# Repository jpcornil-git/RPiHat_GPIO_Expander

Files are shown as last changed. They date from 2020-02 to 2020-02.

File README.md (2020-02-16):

# RPiHat_GPIO_Expander
Main motivation behind this design was to design an input/output system for home automation able to control 230VAC equipments without exposing hazardous voltages (as it is usually the case with popular relay expansion boards) as well as support high current requirements. DIN-rail mount relays meet both requirements and can be controlled using a 24V DC voltage and reasonable current levels. The same 24V voltage can also be used for input devices (buttons, switches …) while offering high noise immunity.  

This Raspberry HAT design allows to control up to 8x DIN-rail mount relays (24VDC, ~25mA coil current) and sense up to 8x 24VDC inputs. It also integrates a 24V->5V DCDC converter that may be used to power the Raspberry motherboard and avoid the need for an additional USB adapter and associated wall plug in the distribution panel. 

This repository includes all design informations (eagle schematic/layout, Gerber, BOM, ...) and related documentation

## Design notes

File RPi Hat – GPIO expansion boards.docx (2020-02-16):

# RPi Hat – GPIO expansion boards (24VDC, 8 inputs + 8 outputs)

## Overview

Main motivation behind this design was to design an input/output system for home automation able to control 230VAC equipments without exposing hazardous voltages (as it is usually the case with popular relay expansion boards) as well as support high current requirements. DIN-rail mount relays meet both requirements and can be controlled using a 24V DC voltage and reasonable current levels. The same 24V voltage can also be used for input devices (buttons, switches …) while offering high noise immunity.

This Raspberry HAT design allows to control up to 8x DIN-rail mount relays (24VDC, ~25mA coil current) and sense up to 8x 24VDC inputs. It also integrates a 24V->5V DCDC converter that may be used to power the Raspberry motherboard and avoid the need for an additional USB adapter and associated wall plug in the distribution panel.

In order to offer robust connections and easy system plug-in/out, Phoenix connectors have been used for signal and power interfaces.

Figure 1: RPi HA 8ch in/out HAT

## Description

The design is based on a MCP23017 I2C-based GPIO expander and integrates:

- One ULN2803 high-voltage Darlington driving up to 8 relay coils for the 8 output ports
- Eight 24V -> 3V3 level shifters for the 8 input ports

Figure 2: Input and output schematic

The I2C address of the MCP23017 can be configured between 0x20 and 0x27 using 3 jumpers (JP2, no jumpers = 0x27).

Reset pin as well as interrupt A and B of the MCP23017 are also available and can optionally be mapped to Raspberry‘s GPIO 25, 24 and 23 respectively using JP1.

## Power supplies

The design is powered directly by the Raspberry’s 3V3 power supply (available from the 2x20 pin header).

The 24V->5V DCDC converter may alternatively be used to power the Raspberry motherboard thru the same pin header avoiding the need for an additional USB adapter. To resolve supply conflicts when both sources are connected, a voltage monitoring circuitry disconnects the 5V DCDC autonomously when power from the motherboard is detected (without supply transients).

This DCDC converter is optional (may be removed from the PCB BOM eventually) and can therefore be disabled by a jumper on JP1 (5V0 PD).

Note that 24VDC and GND signals should always be connected to the external power supply as the freewheeling protection diodes are connected to the 24VDC power supply and relay return currents flow thru GND.

## Cascading option (up to 8x8=64 inputs/outputs)

Multiple expansion boards can be cascaded from a single Raspberry by using the two I2C connectors (carrying 3V3/GND power supply on top of I2C SCL/SDA signals). Each slave device has to be configured with a different I2C address obviously and connected to the common 24VDC/GND for the reasons explained above.

Power consumption extracted from the Raspberry 3V3 is minimal (<1mA/device), high currents being all derived from the 24V supply.

## Connectors

- Inputs and outputs: Phoenix MSTB2.5/8-ST-5.08
- Power supply (24V/GND): Phoenix MSTB2.5/2ST5.08
- I2C: Molex 51065-0400 (header) + 50212-8000 (wire)
- Raspberry: 2x20 female pin header with long pin (min. 10mm height required for the output Phoenix connector sitting above RJ45/USB, e.g. https://www.adafruit.com/product/1979)
- Spacer: min. 12.7mm (10mm + 2.7mm RPi male pin header)

Figure 3: 2x20 female pin header height requirements

## Implementation example

DIN modules references:

- Power supply (24V, 15W) :
  - Meanwell HDR-15-24
- Power relays
  - Unipolar 230VAC, 16A:
    - Finder 4C.01.9.024.0050SPA (relay 46.61.9.024.0040 + base 97.01)
  - Bipolar 230VAC, 8A:
    - Finder 4C.02.9.024.0050SPA (relay 46.52.9.024.0040 + base 97.02)

## I2C access from Raspberry

### Console

Cfr. MPC23017 datasheet (https://www.microchip.com/wwwproducts/en/MCP23017), table 3-5

Check I2C address (0x27 here):

$ i2cdetect -y 1
0 1 2 3 4 5 6 7 8 9 a b c d e f
00: -- -- -- -- -- -- -- -- -- -- -- -- --
10: -- -- -- -- -- -- -- -- -- -- -- -- -- -- -- --
20: -- -- -- -- -- -- -- 27 -- -- -- -- -- -- -- --
30: -- -- -- -- -- -- -- -- -- -- -- -- -- -- -- --
40: -- -- -- -- -- -- -- -- -- -- -- -- -- -- -- --
50: -- -- -- -- -- -- -- -- -- -- -- -- -- -- -- --
60: -- -- -- -- -- -- -- -- -- -- -- -- -- -- -- --
70: -- -- -- -- -- -- -- --

Configure first 8 pins as output (register IODIRA @ 0x0):

$ i2cset -y 1 0x27 0x00 0x00

Set GPIOA[0] to 1 (bit 0 of register OLATA @ 0x14)

$ i2cset -y 1 0x27 0x14 0x01

Read GPIOB inputs (register GPIOB @ 0x13)

$ i2cget -y 1 0x27 0x13
0xff

### Python

Install python-smbus (i2c) package if not done already

$ sudo apt-get install python-smbus

Same operations as above but using python:

$ python
import smbus

bus = smbus.SMBus(1)

bus.write_byte_data(0x27,0x00,0x00)
bus.write_byte_data(0x27,0x14,0x01)
bus.read_byte_data(0x27,0x13)

## HomeAssistant (https://www.home-assistant.io/) support

configuration.yaml:

binary_sensor:
- platform: mcp23017
i2c_address: 0x27
scan_interval: 1
invert_logic: true
pins:
8 : Button_0
9 : Button_1
10: Button_2
11: Button_3
12: Button_4
13: Button_5
14: Button_6
15: Button_7

switch:
- platform: mcp23017
i2c_address: 0x27
pins:
0 : Output_0
1 : Output_1
2 : Output_2
3 : Output_3
4 : Output_4
5 : Output_5
6 : Output_6
7 : Output_7

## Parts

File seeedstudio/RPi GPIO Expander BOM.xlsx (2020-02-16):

Designator | Manufacturer Part Number or Seeed SKU | Qty | Link
R2, R3, R10, R12, R14, R16, R18, R20 | RC0805JR-07100KL | 8 | https://www.mouser.com/Search/Refine.aspx?Keyword=603-RC0805JR-07100KL
C1 | CC0805KRX7R9BB104 | 1 | https://www.mouser.com/Search/Refine.aspx?Keyword=603-CC805KRX7R9BB104
R1, R4, R5, R6, R7, R9, R11, R13, R15, R17, R19, R21 | RC0805JR-0710KL | 12 | https://www.mouser.com/Search/Refine.aspx?Keyword=603-RC0805JR-0710KL
R40, R43 | RC0805FR-0710KL | 2 | https://www.mouser.com/Search/Refine.aspx?Keyword=603-RC0805FR-0710KL
C3, C4 | CC0805KRX7R9BB103 | 2 | https://www.mouser.com/Search/Refine.aspx?Keyword=603-CC805KRX7R9BB103
C5 | C3225X7R1H106M250AC | 1 | https://www.mouser.com/Search/Refine.aspx?Keyword=810-C3225X7R1H106MAC
C2 | CC0805ZKY5V6BB106 | 1 | https://www.mouser.com/Search/Refine.aspx?Keyword=603-CC805ZKY5V6BB106
C7 | 6TPG150M | 1 | https://www.mouser.com/Search/Refine.aspx?Keyword=667-6TPG150M
R8, R22, R23, R24, R25, R26, R27, R28, R29, R42 | RC0805JR-07330RL | 10 | https://www.mouser.com/Search/Refine.aspx?Keyword=603-RC0805JR-07330RL
R38 | RC0805FR-073K24L | 1 | http://www.mouser.com/Search/ProductDetail.aspx?qs=g6xwsc4j%252b%2foDAADmEdN98Q%3d%3d
R30, R31, R32, R33, R34, R35, R36, R37 | RC0805JR-074K7L | 8 | https://www.mouser.com/Search/Refine.aspx?Keyword=603-RC0805JR-074K7L
R39 | RC0805FR-0747KL | 1 | https://www.mouser.com/Search/Refine.aspx?Keyword=603-RC0805FR-0747KL
L1 | CLF10060NIT-470M-D | 1 | https://www.mouser.com/Search/Refine.aspx?Keyword=810-CLF10060NIT470MD
K2, K3 | 53253-0470 | 2 | https://www.mouser.com/Search/Refine.aspx?Keyword=538-53253-0470
R41 | RC0805JR-07680RL | 1 | https://www.mouser.com/Search/Refine.aspx?Keyword=603-RC0805JR-07680RL
Q10 | BCM857BS,115 | 1 | https://www.mouser.com/Search/Refine.aspx?Keyword=771-BCM857BS115
D1, D2, D3, D4, D5, D6, D7, D8 | 17-215SYGC/S530-E2/TR8 | 8 | http://file.elecfans.com/web1/M00/83/01/o4YBAFxJF4-AKNjPAAJW7tn19So845.pdf?filename=17-215SYGC-S530-E2-TR8.pdf
Q9 | DMG2305UX-7 | 1 | https://www.mouser.com/Search/Refine.aspx?Keyword=621-DMG2305UX-7
D9, D10, D11, D12, D13, D14, D15, D16 | 17-215SYGC/S530-E2/TR8 | 8 | http://file.elecfans.com/web1/M00/83/01/o4YBAFxJF4-AKNjPAAJW7tn19So845.pdf?filename=17-215SYGC-S530-E2-TR8.pdf
IC1 | MCP23017SO | 1 | http://ww1.microchip.com/downloads/en/DeviceDoc/21952a.pdf
Q1, Q2, Q3, Q4, Q5, Q6, Q7, Q8 | MMBT3904LT1G(SOT-23) | 8 | https://www.onsemi.com/pub/Collateral/MMBT3904LT1-D.PDF
X2 | MSTBA2 | 1 | https://www.phoenixcontact.com/online/portal/fr?uri=pxc-oc-itemdetail:pid=1757242&library=frfr&tab=1
X1, X3 | MSTBA8 | 2 | https://www.phoenixcontact.com/online/portal/us?uri=pxc-oc-itemdetail:pid=1757307&library=usen&tab=1
K1 | PIN20X2 | 1 | Do Not Install
D17, D18 | 17-215SURC/S530-A2/TR8 | 2 | http://file.elecfans.com/web1/M00/93/B5/pIYBAFzrq_OAZYRuAAKkdEHG_Ws713.pdf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
D19 | SS26FL | 1 | https://www.mouser.com/Search/Refine.aspx?Keyword=512-SS26FL
IC3 | TPS5410_D_8 | 1 | http://www.ti.com/lit/gpn/tps5410
JP1 | TSW-103-07-T-D | 1 | https://www.mouser.com/Search/Refine.aspx?Keyword=200-TSW10307TD
JP2 | TSW-104-07-T-D | 1 | https://www.mouser.com/Search/Refine.aspx?Keyword=200-TSW10407TD
IC2 | ULN2803G-S18-R | 1 | http://file.elecfans.com/web1/M00/98/6A/pIYBAF0UKrmAPMr8AARSGjClQaM748.pdf?filename=ULN2803.pdf)

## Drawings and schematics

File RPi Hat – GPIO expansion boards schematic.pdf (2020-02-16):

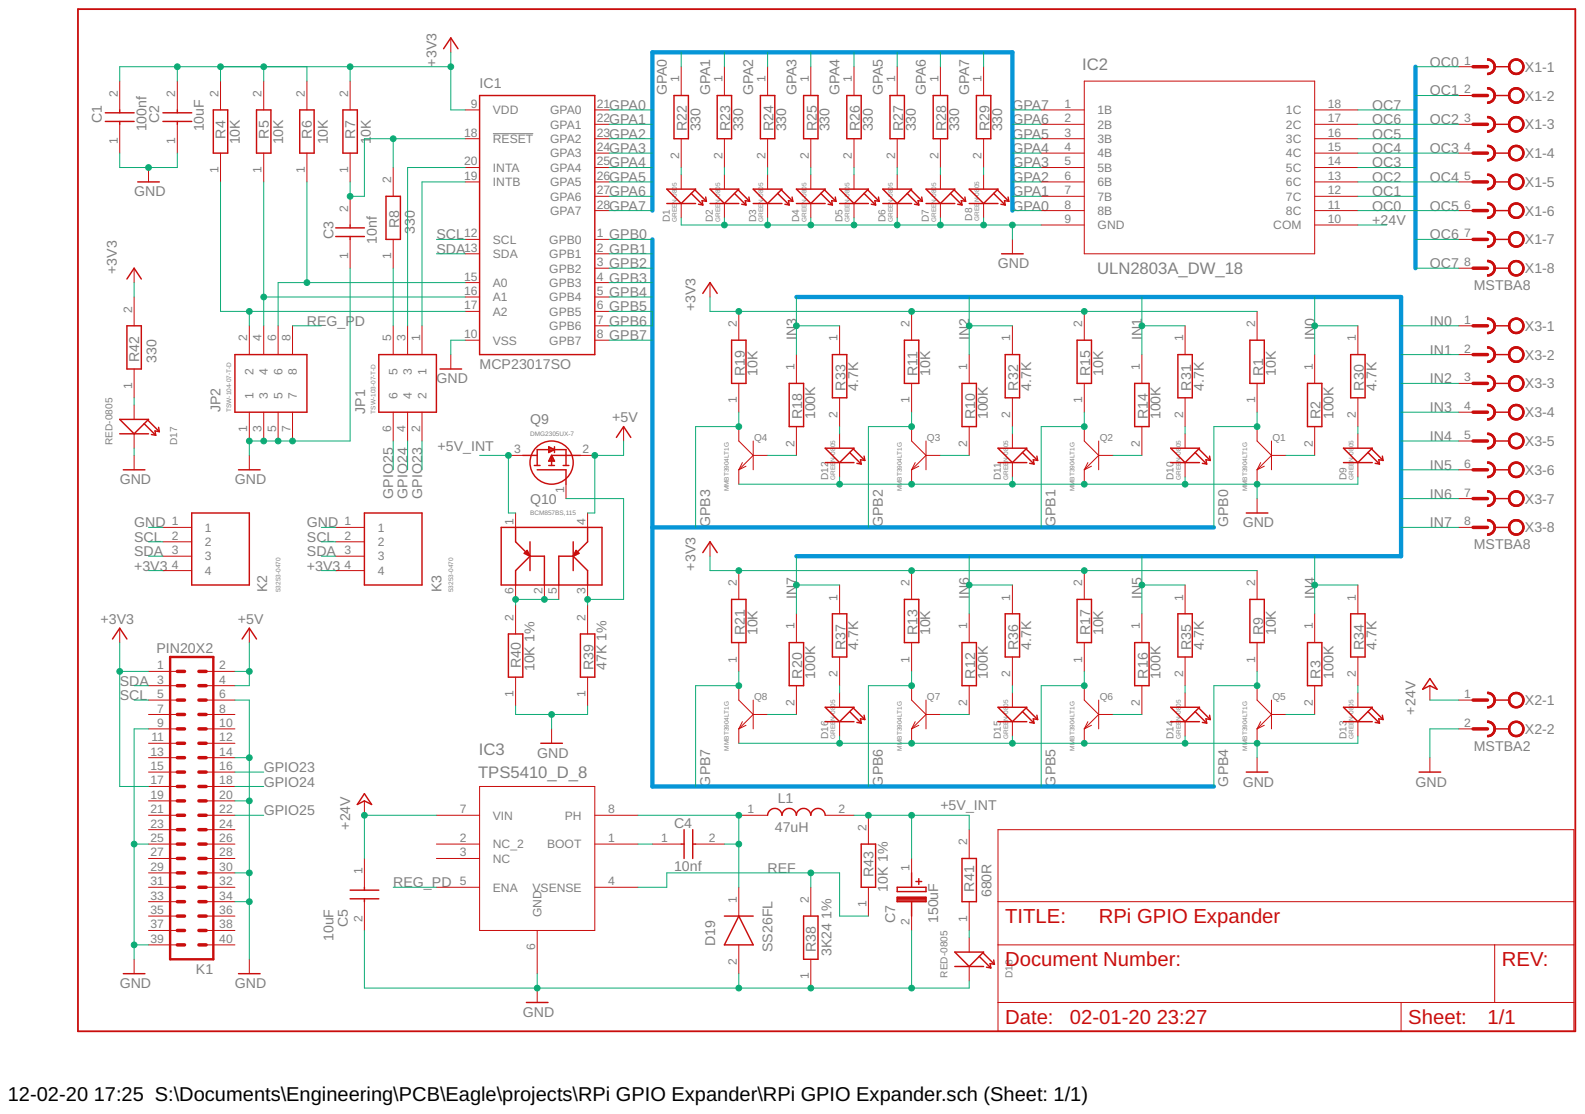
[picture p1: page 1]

GREEN-0805 GREEN-0805 GREEN-0805 GREEN-0805

12-02-20 17:25 S:\Documents\Engineering\PCB\Eagle\projects\RPi GPIO Expander\RPi GPIO Expander.sch (Sheet: 1/1)

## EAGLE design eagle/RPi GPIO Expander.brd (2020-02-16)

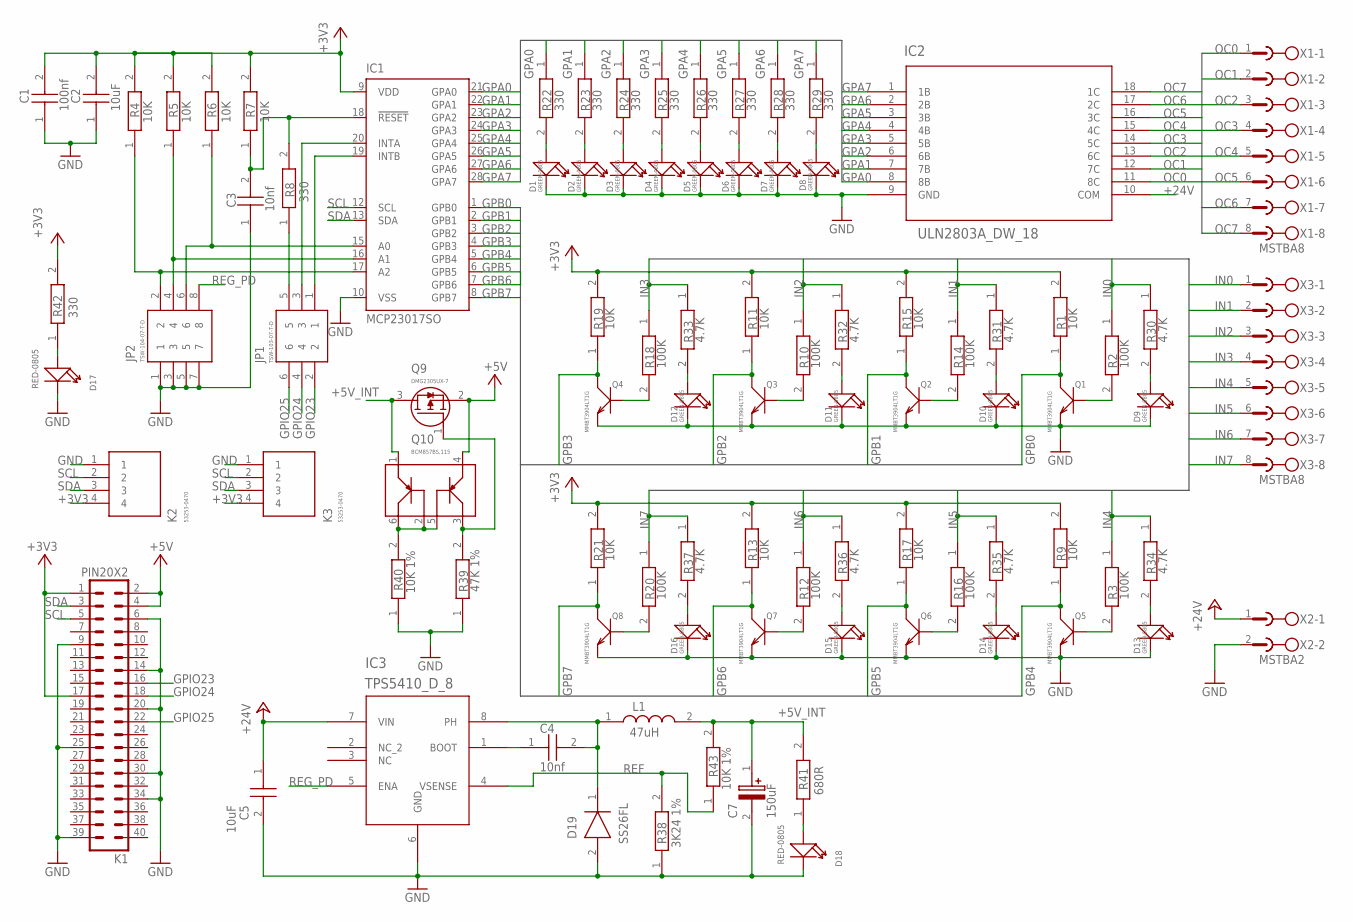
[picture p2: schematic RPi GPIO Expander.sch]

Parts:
C1: 100nf; CAPC2012X95N
C2: 10uF; CAPC2013X145N
C3, C4: 10nf; CAPC2012X135N
C5: 10uF; CAPC3225X230N
C7: 150uF; CAPPM3629X150N
D1, D2, D3, D4, D5, D6, D7, D8, D9, D10, D11, D12, D13, D14, D15, D16: GREEN-0805; LED-0805
D17, D18: RED-0805; LED-0805
D19: SS26FL; SODFL3617X108N
IC1: MCP23017SO; SO28W
IC2: ULN2803A_DW_18; DW18
IC3: TPS5410_D_8; D8
JP1: TSW-103-07-T-D; HDRV6W64P254_2X3_762X495X838P
JP2: TSW-104-07-T-D; HDRV8W64P254_2X4_1016X495X838P
K1: PIN20X2; PIN_20X2
K2, K3: 53253-0470; SHDR4W50P0X200_1X4_1000X365X55
L1: 47uH; INDPM101100X630N
Q1, Q2, Q3, Q4, Q5, Q6, Q7, Q8: MMBT3904LT1G; SOT-23
Q9: DMG2305UX-7; SOT96P240X100-3N
Q10: BCM857BS,115; SOT65P210X110-6N
R1, R4, R5, R6, R7, R9, R11, R13, R15, R17, R19, R21: 10K; RESC2012X60N
R2, R3, R10, R12, R14, R16, R18, R20: 100K; RESC2012X60N
R8, R22, R23, R24, R25, R26, R27, R28, R29, R42: 330; RESC2012X60N
R30, R31, R32, R33, R34, R35, R36, R37: 4.7K; RESC2012X60N
R38: 3K24 1%; RESC2012X60N
R39: 47K 1%; RESC2012X60N
R40, R43: 10K 1%; RESC2012X60N
R41: 680R; RESC2012X60N
X1, X3: MSTBA8
X2: MSTBA2

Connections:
+3V3: C1.2, C2.2 (C2), IC1.9 (VDD), K1.1, K1.17, K2.4, K3.4, R1.2, R4.2, R5.2, R6.2, R7.2, R9.2, R11.2, R13.2, R15.2, R17.2, R19.2, R21.2, R42.2
+5V: K1.2, K1.4, Q9.2 (S), Q10.4
+5V_INT: C7.1 (+), L1.2, Q9.3 (D), Q10.1, R41.2, R43.2
+24V: C5.1, IC2.10 (COM), IC3.7 (VIN), X2.1
GND: C1.1, C2.1 (C1), C3.1, C5.2, C7.2 (-), D1.-, D2.-, D3.-, D4.-, D5.-, D6.-, D7.-, D8.-, D9.-, D10.-, D11.-, D12.-, D13.-, D14.-, D15.-, D16.-, D17.-, D18.-, D19.2 (A), IC1.10 (VSS), IC2.9 (GND), IC3.6 (GND), JP2.1, JP2.3, JP2.5, JP2.7, K1.6, K1.9, K1.14, K1.20, K1.25, K1.30, K1.34, K1.39, K2.1, K3.1, Q1.2 (E), Q2.2 (E), Q3.2 (E), Q4.2 (E), Q5.2 (E), Q6.2 (E), Q7.2 (E), Q8.2 (E), R38.1, R39.1, R40.1, X2.2
GPA0: IC1.21 (GPA0), IC2.8 (8B), R22.1
GPA1: IC1.22 (GPA1), IC2.7 (7B), R23.1
GPA2: IC1.23 (GPA2), IC2.6 (6B), R24.1
GPA3: IC1.24 (GPA3), IC2.5 (5B), R25.1
GPA4: IC1.25 (GPA4), IC2.4 (4B), R26.1
GPA5: IC1.26 (GPA5), IC2.3 (3B), R27.1
GPA6: IC1.27 (GPA6), IC2.2 (2B), R28.1
GPA7: IC1.28 (GPA7), IC2.1 (1B), R29.1
GPB0: IC1.1 (GPB0), Q1.3 (C), R1.1
GPB1: IC1.2 (GPB1), Q2.3 (C), R15.1
GPB2: IC1.3 (GPB2), Q3.3 (C), R11.1
GPB3: IC1.4 (GPB3), Q4.3 (C), R19.1
GPB4: IC1.5 (GPB4), Q5.3 (C), R9.1
GPB5: IC1.6 (GPB5), Q6.3 (C), R17.1
GPB6: IC1.7 (GPB6), Q7.3 (C), R13.1
GPB7: IC1.8 (GPB7), Q8.3 (C), R21.1
GPIO23: JP1.2, K1.16
GPIO24: JP1.4, K1.18
GPIO25: JP1.6, K1.22
IN0: R2.1, R30.1, X3.1
IN1: R14.1, R31.1, X3.2
IN2: R10.1, R32.1, X3.3
IN3: R18.1, R33.1, X3.4
IN4: R3.1, R34.1, X3.5
IN5: R16.1, R35.1, X3.6
IN6: R12.1, R36.1, X3.7
IN7: R20.1, R37.1, X3.8
unnamed: D12.+, R33.2
unnamed: D1.+, R22.2
unnamed: Q1.1 (B), R2.2
unnamed: IC1.19 (INTB), JP1.1
unnamed: JP1.5, R8.1
unnamed: D2.+, R23.2
unnamed: D3.+, R24.2
unnamed: D4.+, R25.2
unnamed: D5.+, R26.2
unnamed: D6.+, R27.2
unnamed: D7.+, R28.2
unnamed: IC1.15 (A0), JP2.6, R6.1
unnamed: IC1.16 (A1), JP2.4, R5.1
unnamed: IC1.17 (A2), JP2.2, R4.1
unnamed: C3.2, IC1.18 (!RESET), R7.1, R8.2
unnamed: IC1.20 (INTA), JP1.3
unnamed: D11.+, R32.2
unnamed: Q5.1 (B), R3.2
unnamed: D10.+, R31.2
unnamed: Q3.1 (B), R10.2
unnamed: D9.+, R30.2
unnamed: Q7.1 (B), R12.2
unnamed: D13.+, R34.2
unnamed: Q2.1 (B), R14.2
unnamed: D14.+, R35.2
unnamed: Q6.1 (B), R16.2
unnamed: D15.+, R36.2
unnamed: Q4.1 (B), R18.2
unnamed: D16.+, R37.2
unnamed: Q8.1 (B), R20.2
unnamed: D8.+, R29.2
unnamed: Q10.2, Q10.5, Q10.6, R40.2
unnamed: C4.2, D19.1 (K), IC3.8 (PH), L1.1
unnamed: D18.+, R41.1
unnamed: C4.1, IC3.1 (BOOT)
unnamed: D17.+, R42.1
unnamed: Q9.1 (G), Q10.3, R39.2
OC0: IC2.11 (8C), X1.1
OC1: IC2.12 (7C), X1.2
OC2: IC2.13 (6C), X1.3
OC3: IC2.14 (5C), X1.4
OC4: IC2.15 (4C), X1.5
OC5: IC2.16 (3C), X1.6
OC6: IC2.17 (2C), X1.7
OC7: IC2.18 (1C), X1.8
REF: IC3.4 (VSENSE), R38.2, R43.1
REG_PD: IC3.5 (ENA), JP2.8
SCL: IC1.12 (SCL), K1.5, K2.2, K3.2
SDA: IC1.13 (SDA), K1.3, K2.3, K3.3

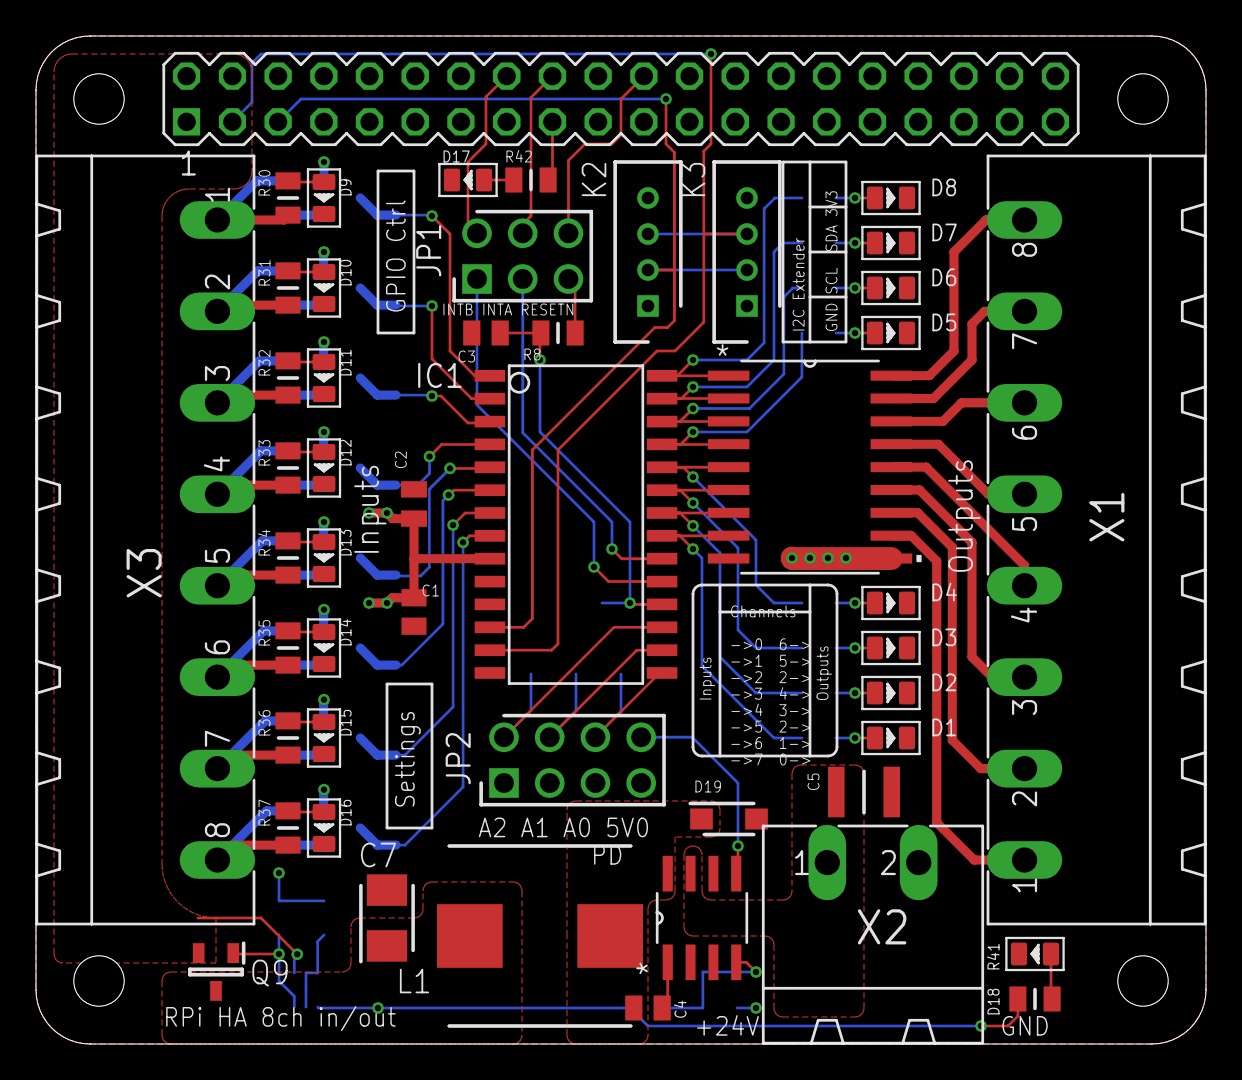
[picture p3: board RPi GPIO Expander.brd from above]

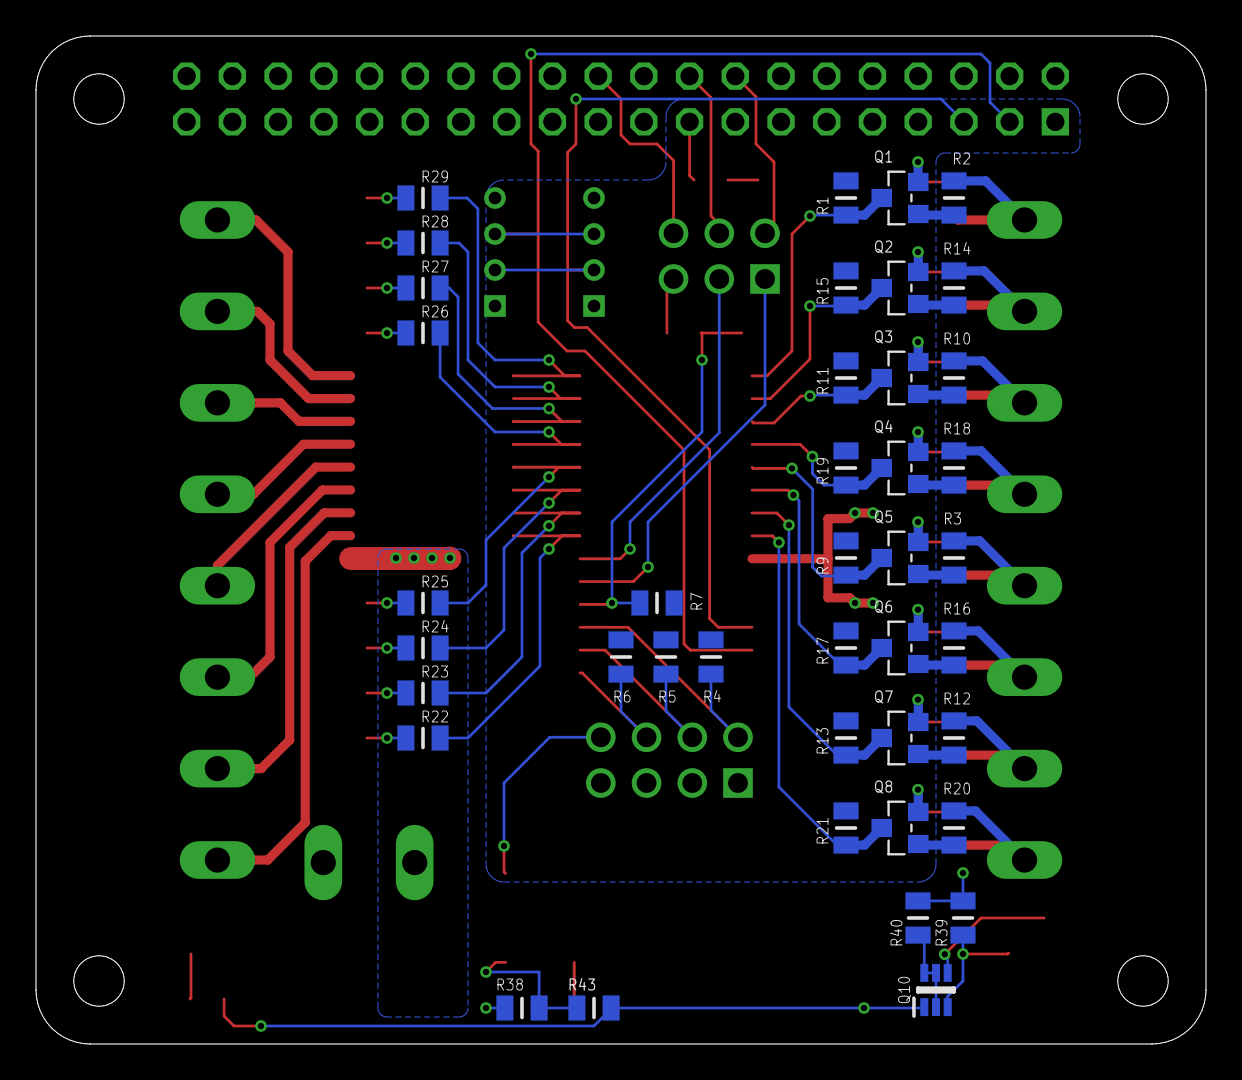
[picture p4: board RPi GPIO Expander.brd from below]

Board: 2 copper layers, 65.0 x 56.0 mm, 90 parts (41 on the bottom side), 81 nets.

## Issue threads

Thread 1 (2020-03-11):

Usage with bistable relays

Misiu, 2020-03-11:
Hi there,

would it be possible to use your board with bistable relays?
my idea is to have lights in room controlled by a bistable relay. The light will be turned on/off by momentary switches around the room (that's the standard usage).
I'd like to plug home assistant to this, so I'll be able to read the state of the relay (is the light on or off) and also change the state (via the web interface)
The idea is to have lights function normally even when automation (raspberry pi with Home Assistant) is down.

jpcornil-git, 2020-03-11:
Sure, you can use the board to control a bistable relay (it would be placed in // with the existing push button) but you will need some additional circuitry to read the state of the relay.

If you goal is to have a system running independently of RPi/HA, you may want to consider KNX devices for switches & button sensors and use HA to address automation/mobile interface/... (HA supports KNX integration)

Cheers
jpc

Misiu, 2020-03-12:
@jpcornil-git thanks for the reply.
I was looking at KNX but it is very expensive.
In my case, I want to control 12 lights in my house. Bistable relay is ideal, but I need a way to control it from Home Assistant.
I was looking at Shelly devices, but I'd like to avoid wireless communication.
I found this tutorial: https://www.instructables.com/id/Latching-Relay-Module/ but I want to avoid building such modules.

Ideally, I'd like to use two of your expansion boards to control and read up to 16 lights.
I must search for din rail relays that do what I need. The problem is I don't know if such a device exists :D

I'll update you if I find something useful.

jpcornil-git, 2020-03-12:
You don't have to build custom modules for this, there are standard DIN rail solutions for set/reset relays , e.g.  with 24VDC coil https://www.tme.eu/ch/fr/details/13.12.0.024.0000/relais-dinstallation/finder/ (there are much more products with a singe coil/push-button)

Cost of 16x of theses relais is comparable to a KNX 16p switch e.g. https://www.eibabo.be/fr/gira/dispositif-d-e-s-combine-pour-knx-maisons-et-batiments-intelligents-automation-103800-eb10828887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

Of course, with  KNX, you need to add (the cost of) a KNX interface for each push button and an IP gateway (~100EUR) to enable communication with HA.

Cheers
jpc

jpcornil-git, 2020-04-28:
No further question/feedbacks -> closing the case

Closed 2020-04-28.
